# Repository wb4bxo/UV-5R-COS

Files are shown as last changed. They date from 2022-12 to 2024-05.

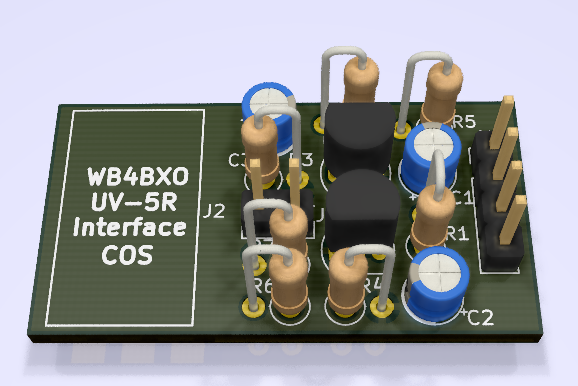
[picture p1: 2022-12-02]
3DSide.png

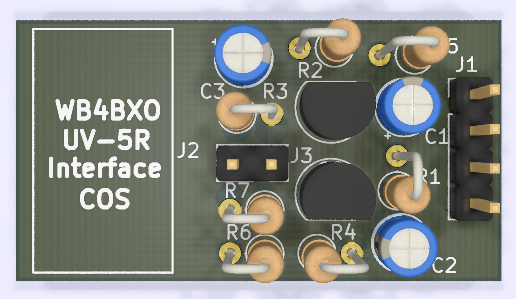
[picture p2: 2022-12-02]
3DTop.png

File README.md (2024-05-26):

# UV-5R-COS
I have put together a little circuit that allows connection to a Baofeng UV-5R HT providing COS without having to open and modify the radio itself. This works great for AllStar, packet, APRS, or most anything that requires a soundcard connection to the radio complete with COS. I have even used this circuit without the sound card to connect to an RC-210 repeater controller.
 
I built the circuit based on the schematic of the UV-5R but I believe most of the Chinese radios will work with it. I have tried it on several different Chinese radios including the Anytone AT-D868UV DMR radio and they all worked fine. However, even though these radios are mimicking the Kenwood two prong speaker/mic connector, this circuit will not work on my Kenwood TH-F6. This is due to the fact that the Chinese radios do not block the DC of the audio amp from reaching the headset, which is why you hear a pop when the squelch opens and closes on these radios, and is what this circuit counts on to turn on Q1 and provide COS. The Kenwood doesn’t work (or have the pop) because it has a blocking capacitor and an MOS switch in the audio line that prevents the DC from coming out the jack. But I’m much happier using a $35 radio for this purpose anyway.
 
I’ve hand etched a couple of boards for it so far and may send it to a board house to make some prettier boards, especially if others are interested in it (I’ve already quoted them and its just too pricey for small quantities, which is why I decided to hand make the few I needed). The boards I have made have some extra pads on the end to allow soldering directly to the audio jacks of one of the EBay sound FOBs, just makes it a bit cleaner than having to cable that side of it, though it still requires the two jumpers to the GPIO lines on the sound chip. Also note that there is an extra connection at Pin 4 on the sound card side that should allow using with an RA-35 or similar that already has the open collector driver for PTT. I have not tried this on an RA-35 but feel confident it would work, my target was primarily the CM108 open board sound FOB you can get on EBay and Amazon.
https://www.ebay.com/itm/CM108-USB-Drive-Free-Sound-Card-Laptop-Computer-External-Sound-Card-Module-New/263928310585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
 
Also note there is no activity detection nor time out timer in this circuit, so I leave the TOT of the attached radio set to something appropriate in case things get hung up in transmit. And as with other interfaces, make sure to keep the RF from the attached HT from getting back into the RPi.

Here is a link to some pictures and such as it progressed. The folder of this version is PCB-02.
https://www.dropbox.com/scl/fo/ijx6qdvklskfgv19kaams/ABsIuqHEEbqoYNm4X1Uc1b4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

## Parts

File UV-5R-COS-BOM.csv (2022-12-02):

Id | Designator | Package | Quantity | Designation | Supplier and ref
1 | J1 | PinHeader_1x04_P2.54mm_Vertical | 1 | Radio
2 | C1,C2,C3 | CP_Radial_D4.0mm_P2.00mm | 3 | 1.5
3 | J3 | PinHeader_2x01_P2.54mm_Vertical | 1 | Aux
4 | J2 | AUDIO JACKS | 1 | Sound Card
5 | R5,R4 | R_Axial_DIN0207_L6.3mm_D2.5mm_P2.54mm_Vertical | 2 | 2K
6 | Q2,Q1 | TO-92_Inline | 2 | 2N3904
7 | R1,R2 | R_Axial_DIN0207_L6.3mm_D2.5mm_P2.54mm_Vertical | 2 | 10K
8 | R7,R3,R6 | R_Axial_DIN0207_L6.3mm_D2.5mm_P2.54mm_Vertical | 3 | 4.7K

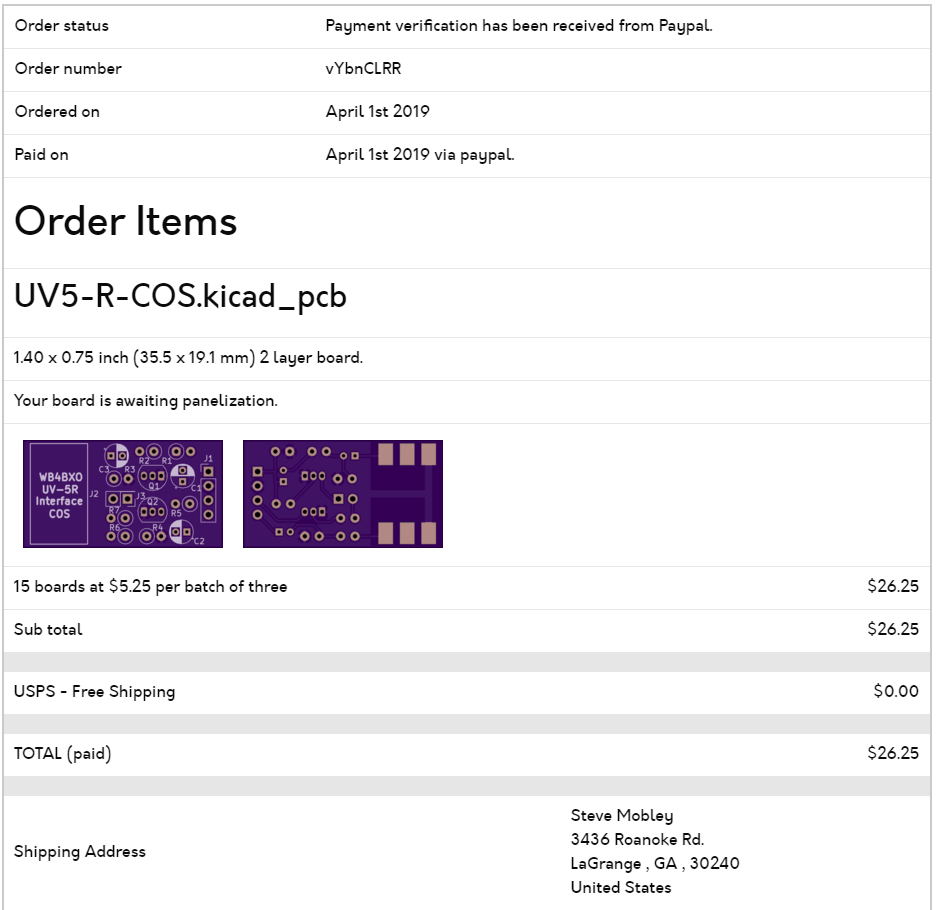
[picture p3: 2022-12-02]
Order190331.png

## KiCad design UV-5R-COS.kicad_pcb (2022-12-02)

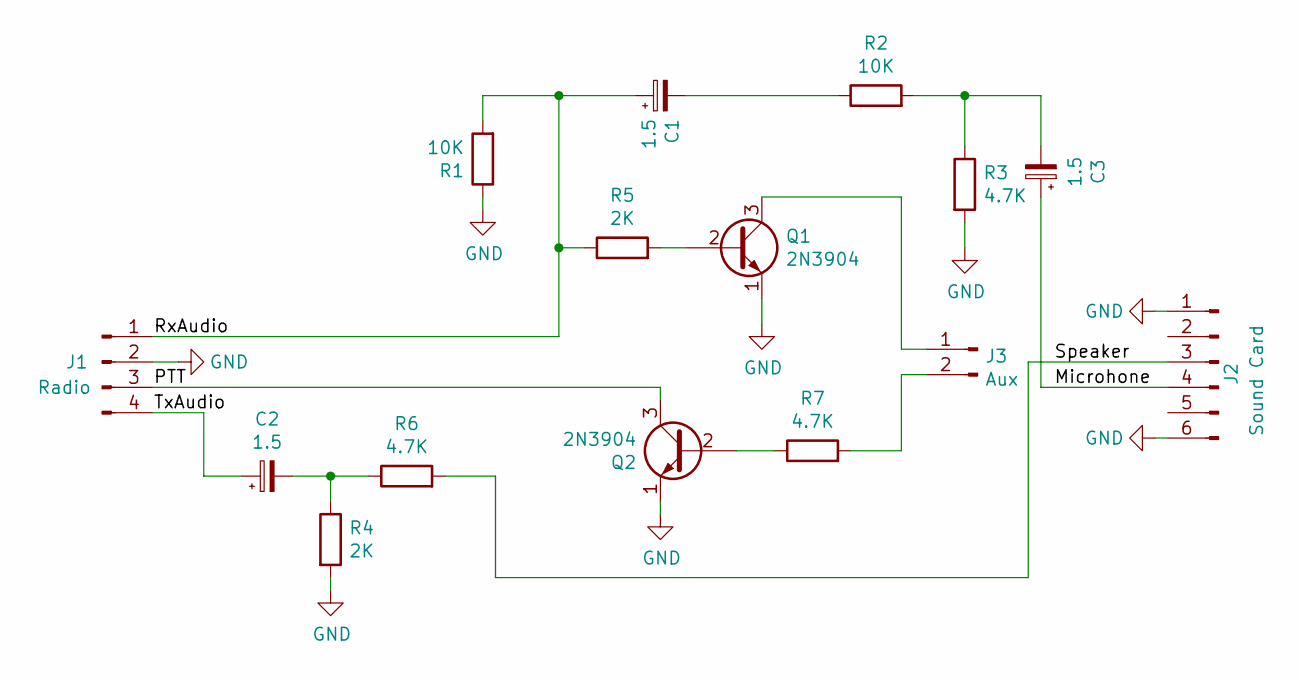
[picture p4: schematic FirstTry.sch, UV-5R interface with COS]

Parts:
C1, C2, C3: 1.5; CP_Radial_D4.0mm_P2.00mm
J1: Radio; PinHeader_1x04_P2.54mm_Vertical
J2: Sound Card; AUDIO JACKS
J3: Aux; PinHeader_2x01_P2.54mm_Vertical
Q1, Q2: 2N3904; TO-92_Inline
R1, R2: 10K; R_Axial_DIN0207_L6.3mm_D2.5mm_P2.54mm_Vertical
R3, R6, R7: 4.7K; R_Axial_DIN0207_L6.3mm_D2.5mm_P2.54mm_Vertical
R4, R5: 2K; R_Axial_DIN0207_L6.3mm_D2.5mm_P2.54mm_Vertical

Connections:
GND: J1.2, J2.1, J2.6, Q1.1 (E), Q2.1 (E), R1.1, R3.2, R4.2
unnamed: C1.1, J1.1, R1.2, R5.1
unnamed: C1.2, R2.1
unnamed: C2.1, J1.4
unnamed: C2.2, R4.1, R6.1
unnamed: C3.1, J2.4
unnamed: C3.2, R2.2, R3.1
unnamed: J1.3, Q2.3 (C)
unnamed: J2.3, R6.2
unnamed: J3.1, Q1.3 (C)
unnamed: J3.2, R7.2
unnamed: Q1.2 (B), R5.2
unnamed: Q2.2 (B), R7.1

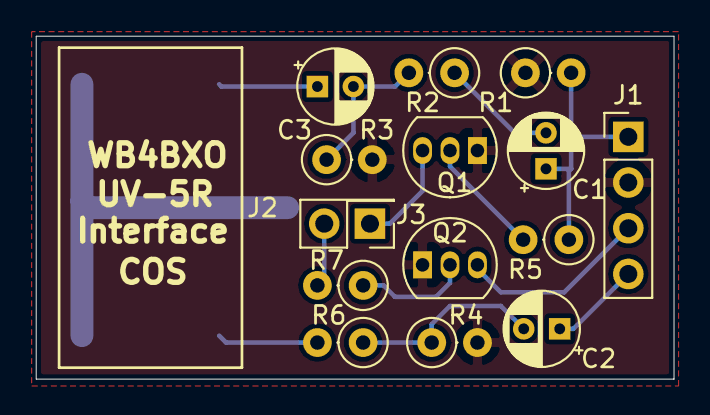
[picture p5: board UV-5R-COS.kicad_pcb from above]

Board: 2 copper layers, 35.4 x 19.0 mm, 15 parts (0 on the bottom side), 13 nets.

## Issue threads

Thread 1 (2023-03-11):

Schematic

tmastersmart, 2023-03-11:
I don't need a board where's the schematic?

wb4bxo, 2024-05-26:
This is the KiCad project. If you open it with KiCad you'll see the schematic. Alternately you can look at the link below and see pictures and pdf files. This board is ALMOST the same as the CMOS version you'll see there.
https://www.dropbox.com/scl/fo/ijx6qdvklskfgv19kaams/ABsIuqHEEbqoYNm4X1Uc1b4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

Closed 2024-07-01.

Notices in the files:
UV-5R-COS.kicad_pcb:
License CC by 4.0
